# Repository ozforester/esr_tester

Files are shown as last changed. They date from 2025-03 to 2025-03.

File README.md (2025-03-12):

# In Circuit ESR Tester
batteries 2xAAA<br>
uc stm32f030f4p6 (cmsis)<br>
opamp mcp6001<br>
switch sn74lvc1g3157dvbr<br>
oled ssd1306 (128x32)<br>
sch and pcb (kicad)<br>
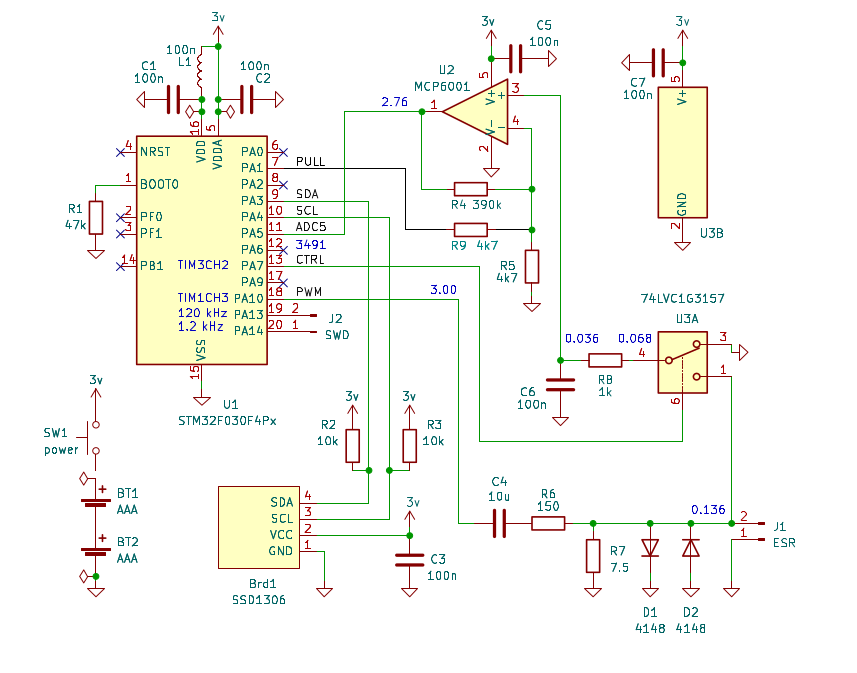
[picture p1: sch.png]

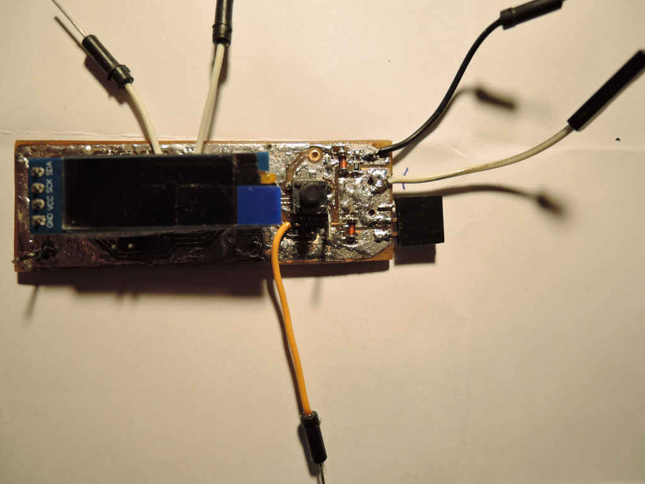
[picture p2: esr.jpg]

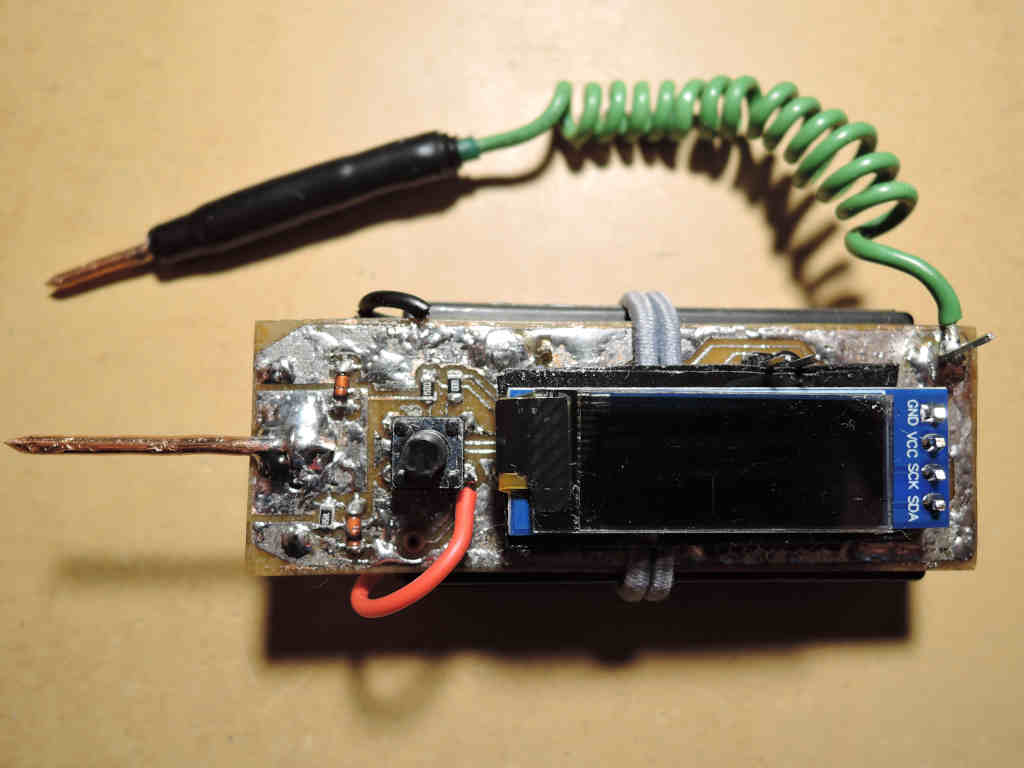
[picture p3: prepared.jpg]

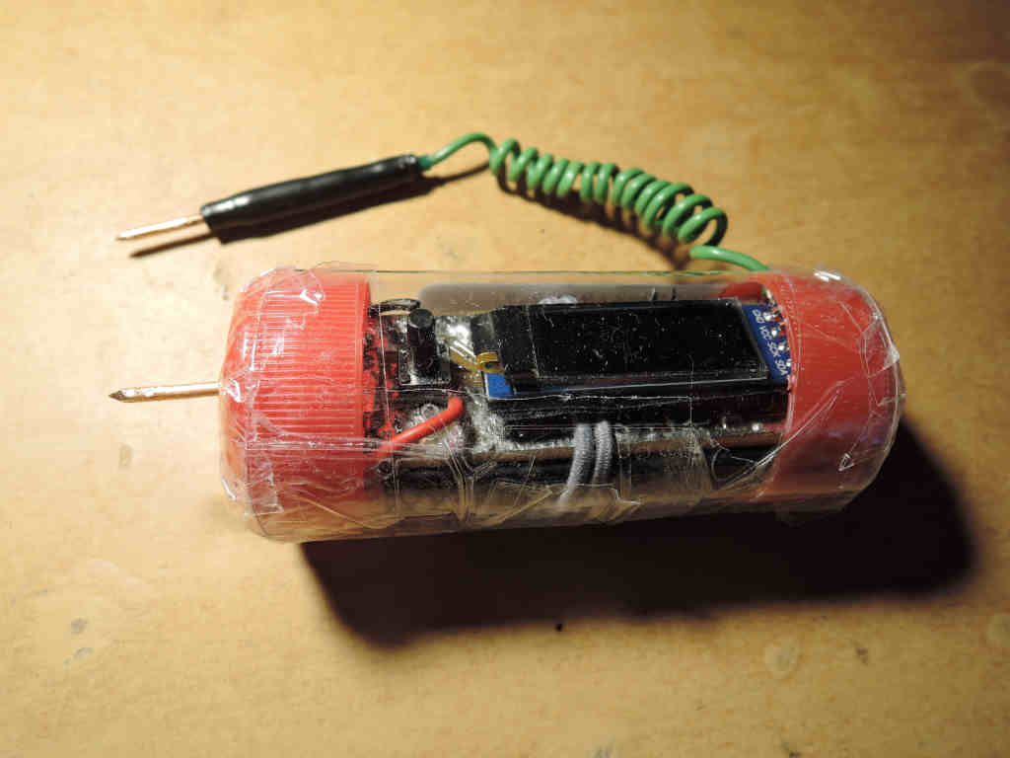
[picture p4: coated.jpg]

Управляемый делитель операционника для тех,<br>
кто решит экспериментировать с измерением<br>
ёмкости (адаптируя частототу шимов под esr)<br>
Пробная директива сдвига на pi/2 между сигналами<br>
(без адаптации) в главном заголовочном файле<br> 
todo проверка конденсатора на кз

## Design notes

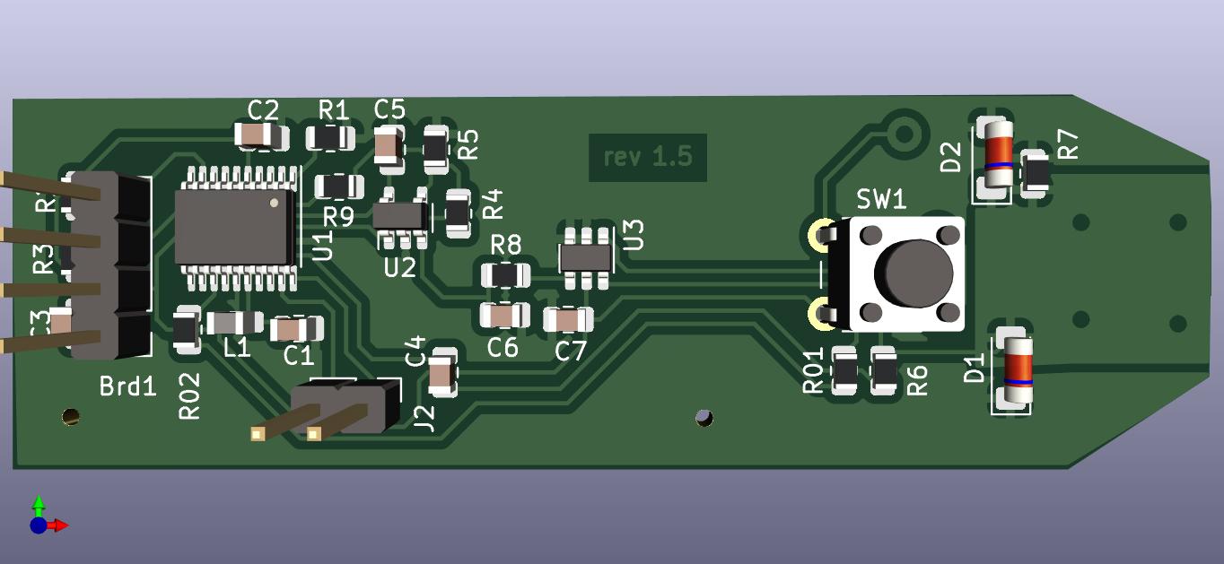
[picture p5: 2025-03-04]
kicad/esr_stm32f030f4.jpg

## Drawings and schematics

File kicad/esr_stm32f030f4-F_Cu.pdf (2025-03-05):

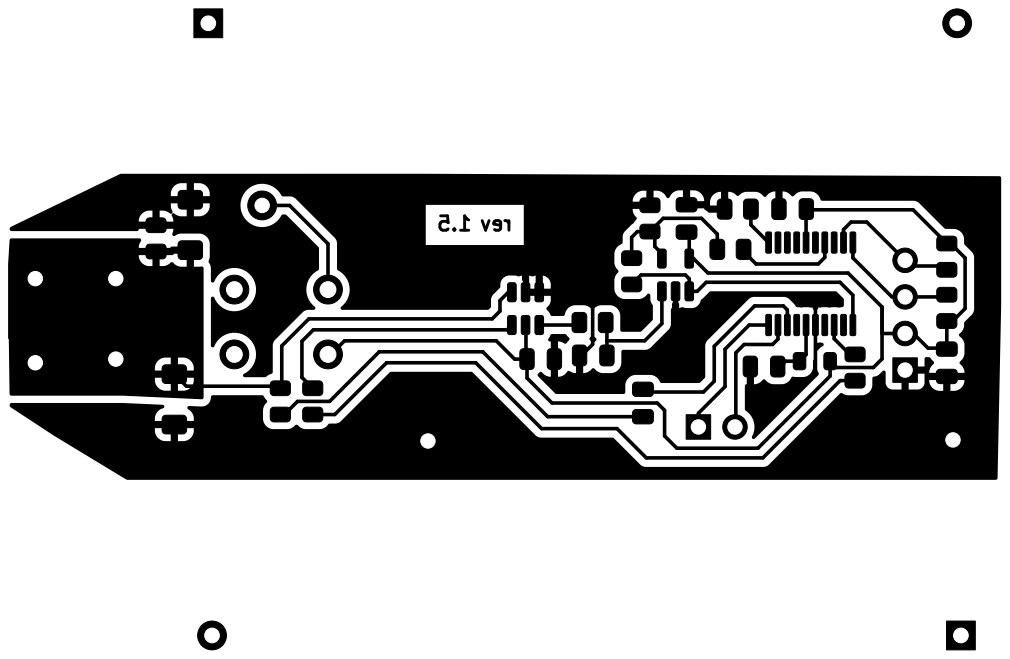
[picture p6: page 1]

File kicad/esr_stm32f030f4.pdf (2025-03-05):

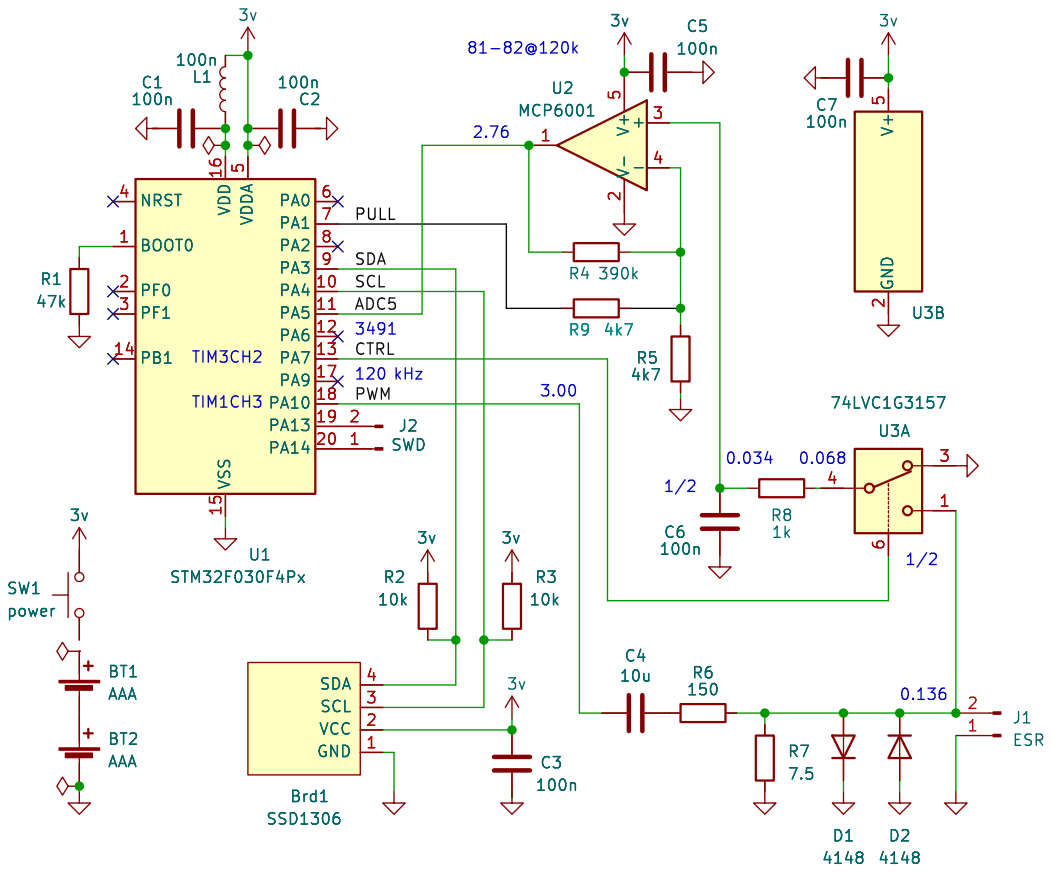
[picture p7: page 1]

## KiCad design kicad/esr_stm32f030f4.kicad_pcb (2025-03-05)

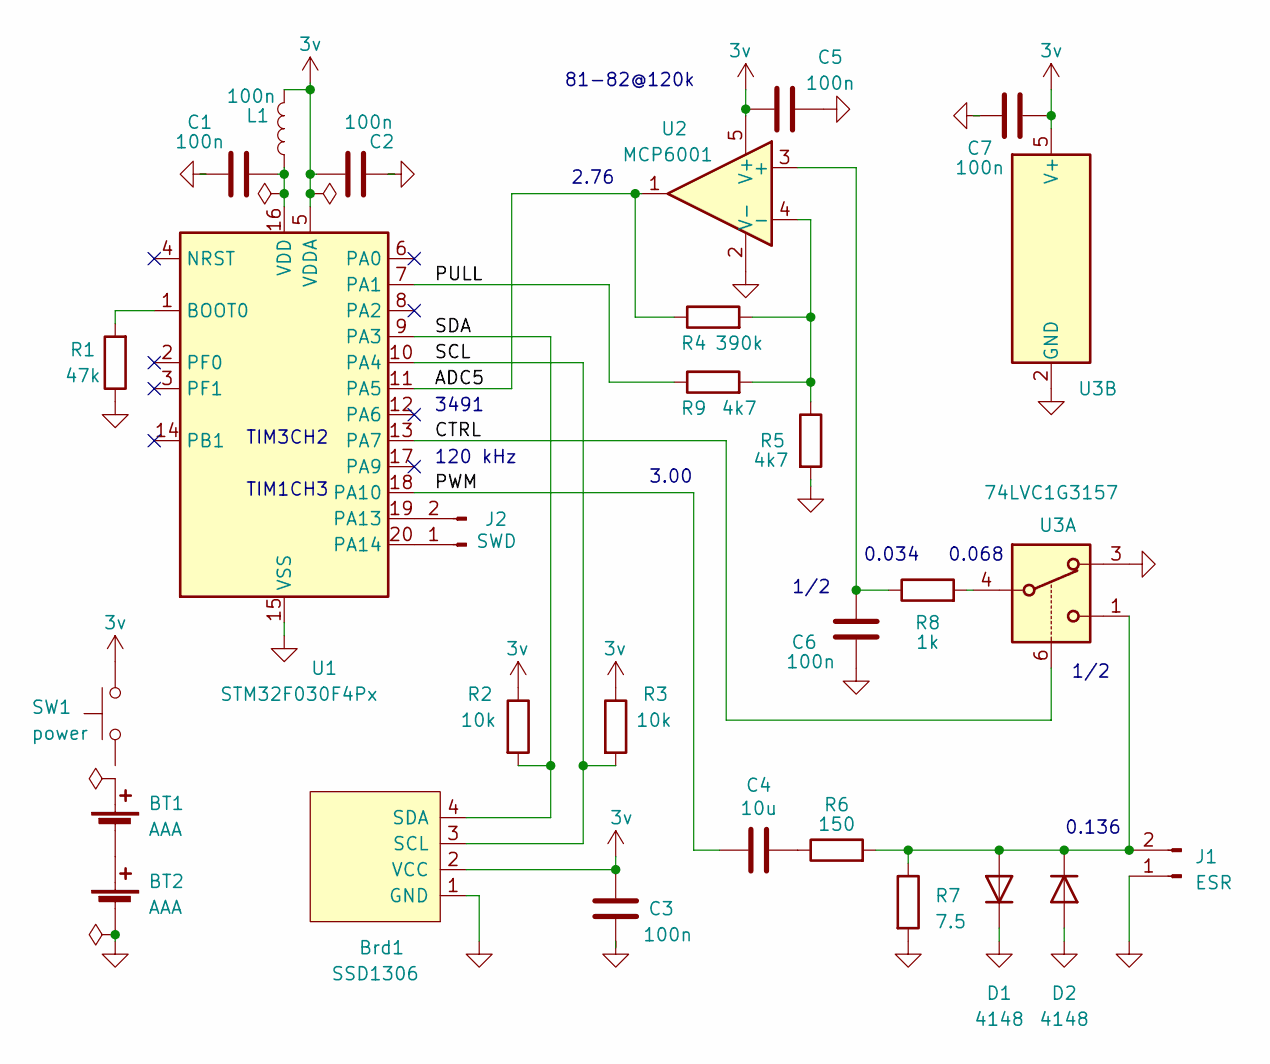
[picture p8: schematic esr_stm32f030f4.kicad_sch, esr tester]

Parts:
BT1, BT2: AAA; BatteryHolder_Keystone_2460_1xAA
Brd1: SSD1306; PinHeader_1x04_P2.54mm_Vertical
C1, C2, C3, C5, C6, C7: 100n; C_0805_2012Metric
C4: 10u; C_0805_2012Metric
D1, D2: 4148; D_MiniMELF
J1: ESR; PinHeader_1x02_P2.54mm_Vertical
J2: SWD; PinHeader_1x02_P2.54mm_Vertical
L1: 100n; L_0805_2012Metric
R1: 47k; R_0805_2012Metric
R2, R3: 10k; R_0805_2012Metric
R4: 390k; R_0805_2012Metric
R5, R9: 4k7; R_0805_2012Metric
R6: 150; R_0805_2012Metric
R7: 7.5; R_0805_2012Metric
R8: 1k; R_0805_2012Metric
SW1: power; SW_PUSH_6mm_H5mm
U1: STM32F030F4Px; TSSOP-20_4.4x6.5mm_P0.65mm
U2: MCP6001; SOT-23-5
U3: 74LVC1G3157; SOT-23-6

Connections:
/ADC5: R4.1, U1.11 (PA5), U2.1
/CTRL: U1.13 (PA7), U3.6; also elsewhere on the board
/PWM: C4.2, U1.18 (PA10)
/SCL: Brd1.3 (SCL), R3.2, U1.10 (PA4)
/SDA: Brd1.4 (SDA), R2.2, U1.9 (PA3)
/SHUNT: R9.1, U1.7 (PA1)
GND: BT2.2 (-), Brd1.1 (GND), C1.2, C2.1, C3.1, C5.2, C6.2, C7.2, D1.1 (K), D2.2 (A), J1.1, R1.1, R5.2, R7.2, U1.15 (VSS), U2.2 (V-), U3.2 (GND), U3.3
unnamed: BT1.1 (+), SW1.1
unnamed: BT1.2 (-), BT2.1 (+)
unnamed: C4.1, R6.1
unnamed: D1.2 (A), D2.1 (K), J1.2, R6.2, R7.1, U3.1
unnamed: J2.1, U1.20 (PA14)
unnamed: J2.2, U1.19 (PA13)
unnamed: R8.2, U3.4
unnamed: R1.2, U1.1 (BOOT0)
unnamed: C1.1, L1.1, U1.16 (VDD)
unnamed: C6.1, R8.1, U2.3 (+)
unnamed: R4.2, R5.1, R9.2, U2.4 (-)
VCC: Brd1.2 (VCC), C2.2, C3.2, C5.1, C7.1, L1.2, R2.1, R3.1, SW1.2, U1.5 (VDDA), U2.5 (V+), U3.5 (V+)

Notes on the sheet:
1/2
120 kHz
0.034
2.76
0.136
3491
3.00
TIM3CH2
81-82@120k
TIM1CH3
0.068

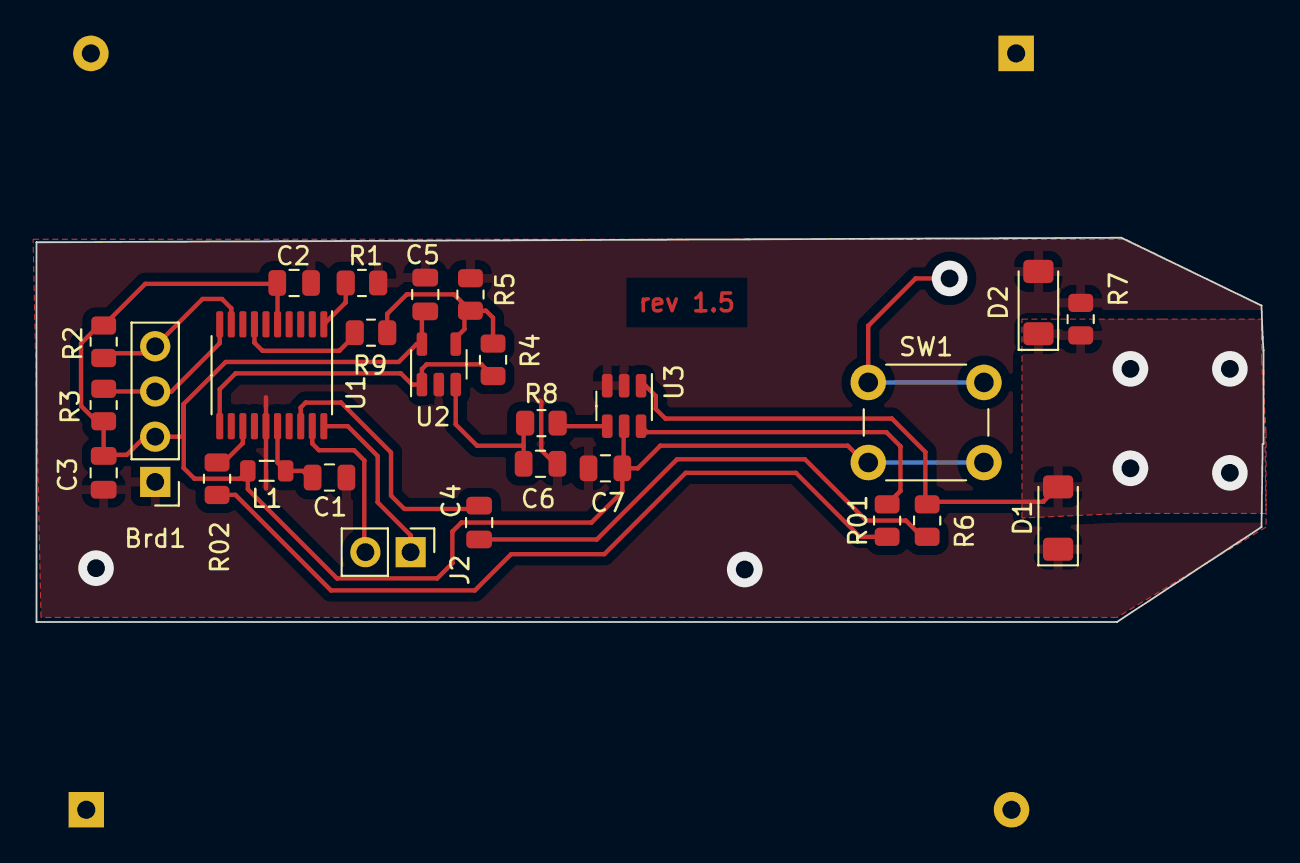
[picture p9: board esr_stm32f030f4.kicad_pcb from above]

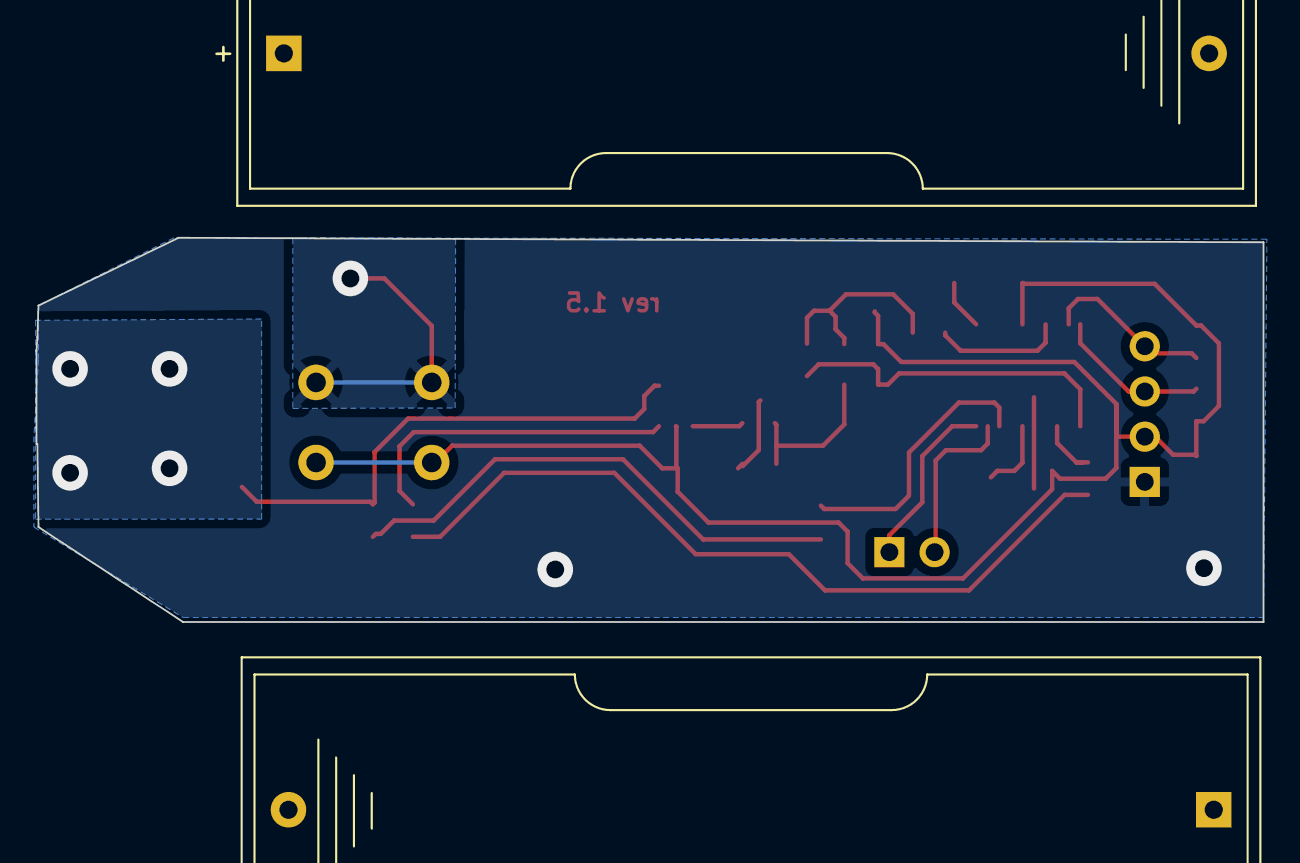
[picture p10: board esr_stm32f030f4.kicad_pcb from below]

Board: 2 copper layers, 68.9 x 21.6 mm, 29 parts (2 on the bottom side), 19 nets.

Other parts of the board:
R01, R02: 0; R_0805_2012Metric

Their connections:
/CTRL: R01.1, R01.2, R02.1, R02.2; also elsewhere on the board

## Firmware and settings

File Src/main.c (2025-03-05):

// Copyright ozforester, MIT License

#include "main.h"

char s[32] ;
volatile int adc;
volatile float uadc ;
volatile int frac ;
volatile float u23 ;
volatile float r23 ;
volatile float r3 ;
volatile float esr ;
volatile float cap ;

int main()
{
	clock_init();
	adc_init();
	GPIO_Init();
	I2C_Init();
	SSD1306_Init();
        timers_init();
	while(1)
		{
                for( volatile uint8_t i = 0 ; i < 100 ; i++ ){ adc += adc_read() ; } adc /= 100 ; // multi
		adc -= NOICE ;
		adc = (adc<0) ? 0 : adc ; // проверка знака
		uadc = adc * VCC / ADB ;
		u23 = uadc / OPA * LPF  ;
		r23 = u23 * R1 / ( PWM - u23 ) - R23 ;
		r3 = r23 * R2 / (R2 - r23) ;
		esr = r3 - PCB ;
                if(esr >= 0 &&  esr < 100 )
			{
	                frac = (esr-(int)esr)*100 ;
	                itoa( (int)esr, s, 10);
	                ssd1306_SetCursor(0, 0);
	                ssd1306_print(FILLER, Font_16x26, White);
	                ssd1306_SetCursor(0, 0);
	                ssd1306_print(s, Font_16x26, White);
	                ssd1306_print(".", Font_16x26, White);
	                if(frac<10) ssd1306_print("0", Font_16x26, White);
	                itoa( frac, s, 10);
	                ssd1306_print(s, Font_16x26, White);
	                ssd1306_UpdateScreen();
			}
		else
			{
	                ssd1306_SetCursor(0, 0);
	                ssd1306_print(FILLER, Font_16x26, White);
	                ssd1306_SetCursor(0, 0);
	                ssd1306_print("-- --", Font_16x26, White);
	                ssd1306_UpdateScreen();
			}
                delay(100);
 		}
}

// EOF

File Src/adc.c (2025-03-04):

// Copyright ozforester, MIT License

#include "stm32f0xx.h"

//void delay(volatile uint32_t);
//char s[20];
//uint16_t adc = 0 ;
//uint32_t uV ;
//uint8_t update = 0 ;

uint16_t adc_read( void )
{
volatile int adc = 0 ;
for( volatile uint8_t i = 0 ; i < 250 ; i++ )
	{ // читаем 250 раз ацп
	while ((ADC1->ISR & ADC_ISR_ADRDY) == 0){}
	ADC1->CR |= ADC_CR_ADSTART;
       	while ((ADC1->ISR & ADC_ISR_EOC) == 0){}
	adc += ADC1->DR ;
	}
return( (uint16_t)(adc/250) ); // возвращаем среднее
}

void adc_init( void )
{ // ADC - ADC5 PA5 (11)
        RCC->AHBENR  |= RCC_AHBENR_GPIOAEN; // clock port A
        GPIOA->MODER  &= ~GPIO_MODER_MODER5; // reset PA5
        GPIOA->MODER  |= GPIO_MODER_MODER5_0|GPIO_MODER_MODER5_1; // PA5 Analog mode
        RCC->APB2ENR |= RCC_APB2ENR_ADCEN ;
        ADC1->CHSELR = ADC_CHSELR_CHSEL5 ; // channel 5
	//ADC1->CHSELR = ADC_CHSELR_CHSEL17 ; // Vref
	//ADC->CCR |= ADC_CCR_VREFEN ;
	ADC1->CFGR2 |= ADC_CFGR2_CKMODE_1 ; // PCLK/4 sync
	//ADC1->SMPR |= ADC_SMPR_SMP_0 | ADC_SMPR_SMP_1 | ADC_SMPR_SMP_2; // slow sampling
        ADC1->SMPR |= ADC_SMPR_SMP_0; // fast sampling
	if ((ADC1->CR & ADC_CR_ADEN) != 0) ADC1->CR |= ADC_CR_ADDIS;
	while ((ADC1->CR & ADC_CR_ADEN) != 0){}
	ADC1->CR |= ADC_CR_ADCAL; // calibration start
	while ((ADC1->CR & ADC_CR_ADCAL) != 0){} // calibration finish
	if ((ADC1->ISR & ADC_ISR_ADRDY) != 0) ADC1->ISR |= ADC_ISR_ADRDY; // enable
	ADC1->CR |= ADC_CR_ADEN; // enable
	while ((ADC1->ISR & ADC_ISR_ADRDY) == 0){} // wait till ready for request
}

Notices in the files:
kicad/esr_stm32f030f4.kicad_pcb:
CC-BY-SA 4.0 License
